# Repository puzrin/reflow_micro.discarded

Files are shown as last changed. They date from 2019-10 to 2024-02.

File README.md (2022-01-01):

Reflow Micro Table
==================




**WIP**

> Simple to build & compact table for hobby projects reflow assembly.

This tool helps to build modern and complicated electronic devices at home.
It's very small, and ideally suits for hobbyists, who assemble PCBs from time to
time an don't wish to keep big reflowers from microwave ovens.

Working area is up to 70\*60mm. That's enougth for almost all hobby PCBs with
SMD components.

- [EasyEDA project page](https://easyeda.com/reflow/reflow-usb-pd-ext) -
  Schematic & PCB. Order everything in couple of clicks.
- [Thingiverse page](https://www.thingiverse.com/thing:4165226) - Case drafts
  for 3d-printer.

Also see project page on [hackaday.io](https://hackaday.io/project/168063-reflow-micro-table).
Until WIP, it tracks progress and has useful tips in build logs.

## Build & usage

- [Assembly guide](doc/assembly.md)
- [User manual](doc/manual.md)

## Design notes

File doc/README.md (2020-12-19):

## Content

- **[assembly.md](assembly.md)** - assembl guide.
- **[heater_assembly.md](troubleshooting.md)** - separate guide for heater build.
- **[manual.md](development.md)** - usage manual.

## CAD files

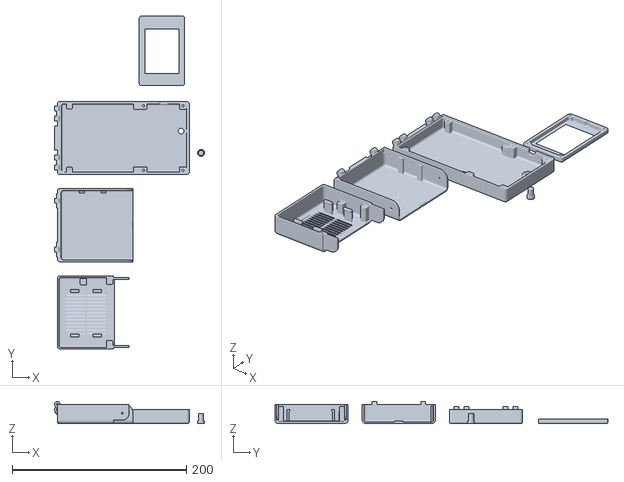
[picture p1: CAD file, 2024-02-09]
3dprint/case.stl
172.3 x 382.0 x 25.4

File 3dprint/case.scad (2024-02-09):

// - Глубину болтов уточнить
include <utils.scad>;

//======================================================================
// Update if other inserts used
// For example, D3.2*3mm
insert_d = 3.6;
insert_h = 4;

magnet_d = 5;
magnet_h = 3;
magnet_x_ofs = 2;
//======================================================================


e = 0.01;
2e = 0.02;

$fn = $preview ? 12 : 48;

wall = 2;
hinges_wall = 4;
right_wall = 2.5;

pcb_wx = 145;
pcb_wy = 80;
pcb_margin = 0.25;
pcb_top_margin = 0.2; // extra space for better close of top cap
pcb_h  = 1.6 + pcb_top_margin;

tray_wx = pcb_wx + hinges_wall + right_wall;
tray_wy = pcb_wy + 2*wall;
tray_h  = 16;

tray_inner_h  = tray_h - wall - pcb_h;

cap1_wx = 87;
cap2_wx = tray_wx - cap1_wx;

cap_inner_h = 20;
cap_h = cap_inner_h + wall;

hinges_d = 6.6;
hinges_shaft_d = 2;
hinges_full_w = 28.0;
hinges_w = 17.0;
hinges_inter_gap = 0.2;
hinges_gap = 0.4;
hinges_section_w = (hinges_w - hinges_inter_gap*2)/3;
hinges_shift = tray_wy/2 - hinges_full_w/2;
hinges_z_correction = 0.1; // Extra Z offset for better case closing

cap_display_mounts_x_shift = -0.0;
cap_display_wx = 52;
cap_display_wy = pcb_wy;
cap_display_inner_h = 4.2;
cap_display_top_wall = 1;
cap_display_h = cap_display_inner_h + cap_display_top_wall;
cap_display_wall = 3;
cap_display_x_inserts_space = 140 - 95;

cap_display_view_wx = 39;
cap_display_view_wy = 51;

case_r_vert = 3;
case_r_bottom = 2;
case_r_top = 4;

btn_base_h = 3;
btn_d = 6.0;
btn_guide_d = btn_d + 0.5 + 6;
pcb_btn_h = 2.7; // Height of button's top point on PCB

module pcb_top(ofs = 0) { tr_y(ofs + pcb_wy/2) children(); }
module pcb_bottom(ofs = 0) { tr_y(ofs - pcb_wy/2) children(); }
module pcb_left(ofs = 0) { tr_x(ofs - tray_wx/2 + hinges_wall) children(); }
module pcb_right(ofs = 0) { tr_x(ofs - tray_wx/2 + hinges_wall + pcb_wx) children(); }

module case_left(ofs = 0) { tr_x(ofs - tray_wx/2) children(); }
module case_right(ofs = 0) { tr_x(ofs + tray_wx/2) children(); }
module case_top(ofs = 0) { tr_y(ofs + tray_wy/2) children(); }
module case_bottom(ofs = 0) { tr_y(ofs - tray_wy/2) children(); }


module m2_screw_hole() {
    translate([0, 0, -e]) {
        cylinder(10, d = 2);
        translate([0, 0, 0.1-e]) cylinder(h = 2, d1 = 4, d2 = 0);
        // Make head outer part long for deep holes
        translate([0, 0, 0.1]) mirror([0, 0, 1]) cylinder(30, d = 4);
    }

}

// Relaxed hole for M2 flat - D 5mm + 2.5mm
module m2_screw_hole_wide() {
    translate([0, 0, -e]) {
        cylinder(10, d = 2.5);
        // Create bigger cone, for extra head dia
        translate([0, 0, 0.1-e-0.236]) cylinder(h = 2.236, d1 = 5, d2 = 0);
        // Make head outer part long for deep holes
        translate([0, 0, 0.1-0.236]) mirror([0, 0, 1]) cylinder(30, d = 5);
    }

}


module fan50_latch(width = 10) {
    translate([width/2, 0.2, -e])
    rotate([0, -90, 0])
    linear_extrude(width)
    polygon([
        [0, 0],
        [11.3, 0],
        [12.8, -1.5],
        [14, -1.5],
        [14, 2],
        [0, 2]
    ]);
}

module fan50_guides() {
    translate([0, -1, 0]) {
        translate([-13, 25, wall]) fan50_latch();
        mirror([1, 0, 0]) translate([-13, 25, wall]) fan50_latch();
        mirror([0, 1, 0]) translate([-13, 25, wall]) fan50_latch();
        rotate([0, 0, 180]) translate([-13, 25, wall]) fan50_latch();

        translate([25, -10, wall - e])
        cube([1.5, 20, 1]);

        mirror([1, 0, 0])
        translate([25, -10, wall - e])
        cube([1.5, 20, 1]);
    }
}

module fan50_hole() {
    rotate([0, 0, -90])
    skew([ 0, 50, 0, 0, 0, 0])
    translate([0, 0, -e])
    rcube([46, 46, wall + 2e], r = 2);
}

module fan50_grill() {
    rotate([0, 0, -90])
    skew([ 0, 50, 0, 0, 0, 0])
    for(i = [-21:4.0:20]) {
        translate([i, -25, 0]) cube([2, 50, 2]);
    }

    translate([-1, -27, 0]) cube([2, 54, 2]);
}

module hinges_add() {
    rotate([-90, 0, 0])
    tr_z(-hinges_w/2)
    hull() {
        cylinder(hinges_w, d = hinges_d);
        cube([hinges_d/2, hinges_d/sqrt(2), hinges_w]);
    }
}

module hinges_substract(second = false) {
    rotate([-90, 0, 0]) {
        // through hole
        cylinder(hinges_w, d = hinges_shaft_d+e, center = true);
        // screw head space
        translate([0, 0, hinges_w/2-e])
        cylinder((hinges_full_w-hinges_w)/2+2e, d = 5.5);
        // screw nut space
        mirror([0, 0, 1])
        translate([0, 0, hinges_w/2-e])
        cylinder((hinges_full_w-hinges_w)/2+2e, d = 5.5);

        if (second == false) {
            cylinder(
                hinges_section_w + hinges_inter_gap*2,
                d = hinges_d + hinges_gap*2,
                center = true
            );
        } else {
            tr_z(hinges_section_w + hinges_inter_gap)
            cylinder(
                hinges_section_w + hinges_inter_gap*2,
                d = hinges_d + hinges_gap*2,
                center = true
            );

            mirror([0, 0, 1])
            tr_z(hinges_section_w + hinges_inter_gap)
            cylinder(
                hinges_section_w + hinges_inter_gap*2,
                d = hinges_d + hinges_gap*2,
                center = true
            );
        }
    }
}

module cap2_hinge() {
    margin = 2;

    rotate_x(90)
    difference() {
        linear_extrude(2)
        hull() {
            translate([-wall, wall + margin]) square(e);
            translate([-wall, cap_h]) square(e);
            translate([cap_inner_h - margin, cap_h]) square(e);

            translate([cap_inner_h/2, cap_inner_h/2+wall, 0])
            circle(cap_inner_h/2 - margin);
        };

        translate([cap_inner_h/2, cap_inner_h/2 + wall, 0])
        cylinder(wall*4, d=2, center=true);
    }
}

module tray_pcb_support(h = tray_h-pcb_h) {
    difference() {
        rcube([7, 7, h], r=1);

        translate([0, 0, h + e])
        mirror([0, 0, 1]) {
            cylinder(insert_h, d = insert_d);
            cylinder(insert_h+5, d = 2.5);
        }
    }
}

module wire_latch() {
    h = cap_h-2;

    rotate([0, 90, 0])
    linear_extrude(6)
    polygon([
        [0, 0],
        [-h, 0],
        [-h, 2],
        [-h+1, 2.5],
        [-h+2, 2],
        [0, 2]
    ]);
}

module magnet_holder(h = 10, wx = 7, wy = 7, md = 5, mh = 3) {
    difference() {
        rcube([wx, wy, h - mh + 0.5]);
        tr_z(h - mh - 0.2) cylinder(h = mh+10, d = md+0.5);
    }
}

module _tray_base() {
    difference() {
        rcube(
            [tray_wx, tray_wy, tray_h],
            r = case_r_vert,
            rbottom = case_r_bottom
        );

        pcb_left(1) pcb_bottom(1) tr_z(wall)
        rcube([pcb_wx-2, pcb_wy-2, tray_h], r=2, rbottom=case_r_bottom, center=false);

        pcb_bottom(-pcb_margin) pcb_left(-pcb_margin) tr_z(tray_h-pcb_h)
        rcube(
            [pcb_wx+pcb_margin*2, pcb_wy+pcb_margin*2, pcb_h+e],
            center=false,
            r=0.01
        );
    }
}


module tray() {
    difference() {
        union() {
            _tray_base();

            // PCB + Display supports (solid, no holes)
            pcb_right(-5) pcb_bottom(3) tr_z(wall)
            rcube([8, 8, tray_h-pcb_h - wall + e]);

            mirror_y()
            pcb_right(-5) pcb_bottom(3) tr_z(wall)
            rcube([8, 8, tray_h-pcb_h - wall + e]);

            pcb_right(-50) pcb_bottom(3) tr_z(wall)
            rcube([8, 8, tray_h-pcb_h - wall + e]);

            mirror_y()
            pcb_right(-50) pcb_bottom(3) tr_z(wall)
            rcube([8, 8, tray_h-pcb_h - wall + e]);

            // Boot0 button guide
            // Height = inner - btn_height - btn_base_h - safety_space
            pcb_right(-7) pcb_top(-32)
            cylinder((tray_h - pcb_h) - pcb_btn_h - btn_base_h - 0.2, d=btn_guide_d);

            // Hinges addons
            case_left() tr_y(hinges_shift) tr_z(tray_h)
            hinges_add();

            mirror_y()
            case_left() tr_y(hinges_shift) tr_z(tray_h)
            hinges_add();

            // Hinge angle limiter
            stopper_w = tray_wy - hinges_full_w*2;
            case_left() tr_z(tray_h)
            rotate_x(90) tr_z(-stopper_w/2)
            linear_extrude(stopper_w)
            polygon([[0,0], [-3,-3.5], [0,-6]]);

            /*case_left() tr_z(tray_h - hinges_d/2)
            rotate([90, 45, 0])
            cube([hinges_d/sqrt(2), hinges_d/sqrt(2), tray_wy - 2*hinges_full_w], center=true);*/
        }

        // Fan wire slot
        pcb_left() pcb_bottom() tr_z(tray_h-pcb_h-5+e)
        cube([4, 2.6, 10]);

        // Boot0 button guide hole
        pcb_right(-7) pcb_top(-32) tr_z(-e)
        cylinder(tray_h, d=btn_d+0.5);

        // Holes in supports for 8mm M2 screws (with 3.3mm display cap inserts)
        pcb_right(-5) pcb_bottom(3) tr_z(tray_h - (8-3.3))
        m2_screw_hole_wide();

        mirror_y()
        pcb_right(-5) pcb_bottom(3) tr_z(tray_h - (8-3.3))
        m2_screw_hole_wide();
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

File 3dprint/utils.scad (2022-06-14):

e = 0.01;
2e = 0.02;


module qfillet(h, r) {
    difference () {
        translate([-e, -e, 0]) cube([r+e, r+e, h]);
        translate([r, r, -e]) cylinder(h+2e, r = r);
    }
}

module torus(r1, r2, $fn = $fn) {
    rotate_extrude(convexity=2, $fn=$fn)
    difference() {
        translate([r1 - r2, 0, 0]) circle(r=r2, $fn=$fn);
        translate([-r2, 0, 0]) square(r2*2, true);
    }
}

module _hooled_toruses(x, y, r_xy, r_z) {
    translate([r_xy, r_xy, 0]) torus(r_xy, r_z);
    translate([x-r_xy, r_xy, 0]) torus(r_xy, r_z);
    translate([r_xy, y-r_xy, 0]) torus(r_xy, r_z);
    translate([x-r_xy, y-r_xy, 0]) torus(r_xy, r_z);
    
    translate([r_z, r_xy, 0]) rotate([-90, 0, 0]) cylinder(y-r_xy*2, r=r_z);
    translate([x-r_z, r_xy, 0]) rotate([-90, 0, 0]) cylinder(y-r_xy*2, r=r_z);
    translate([r_xy, r_z, 0]) rotate([0, 90, 0]) cylinder(x-r_xy*2, r=r_z);
    translate([r_xy, y-r_z, 0]) rotate([0, 90, 0]) cylinder(x-r_xy*2, r=r_z);
    
    translate([r_z, r_z, -r_z])
    rcube([x-r_z*2, y-r_z*2, r_z*2], r = r_xy-r_z, center = false);
}


module rcube(size = [10, 10, 10], center = true, r = 1, rtop = 0, rbottom = 0) {
    x = size[0]; y = size[1]; h = size[2];

    tx = center ? -x/2 : 0;
    ty = center ? -y/2 : 0;

    translate([tx, ty, 0]) {
        if (rtop == 0 && rbottom == 0) {
            translate([r, r, 0]) cylinder(h, r = r);
            translate([x-r, r, 0]) cylinder(h, r = r);
            translate([r, y-r, 0]) cylinder(h, r = r);
            translate([x-r, y-r, 0]) cylinder(h, r = r);
            translate([0, r, 0]) cube([x, y-r*2, h]);
            translate([r, 0, 0]) cube([x-r*2, y, h]);
        }
        if (rtop > 0 && rbottom == 0) {
            translate([0, 0, h-rtop]) _hooled_toruses(x, y, r, rtop);
            rcube([x, y, h-rtop], r = r, center = false);
        }
        if (rtop == 0 && rbottom > 0) {
            translate([0, 0, rbottom]) _hooled_toruses(x, y, r, rbottom);
            translate([0, 0, rbottom])
            rcube([x, y, h-rbottom], r = r, center = false);
        }
        if (rtop > 0 && rbottom > 0) {
            translate([0, 0, h-rtop]) _hooled_toruses(x, y, r, rtop);
            translate([0, 0, rbottom]) _hooled_toruses(x, y, r, rbottom);
            translate([0, 0, rbottom])
            rcube([x, y, h-rbottom-rtop], r = r, center = false);            
        }
    }
}

// skew takes an array of six angles:
// [ x:y, x:z, y:x, y:z, z:x, z:y ]
module skew(dims) {
    matrix = [
        [ 1, tan(dims[0]), tan(dims[1]), 0 ],
        [ tan(dims[2]), 1, tan(dims[3]), 0 ],
        [ tan(dims[4]), tan(dims[5]), 1, 0 ],
        [ 0, 0, 0, 1 ]
    ];
    multmatrix(matrix) children();
}

module rotate_x(angle) { rotate([angle, 0, 0]) children(); }
module rotate_y(angle) { rotate([0, angle, 0]) children(); }
module rotate_z(angle) { rotate([0, 0, angle]) children(); }

module tr_x(ofs) { translate([ofs, 0, 0]) children(); }
module tr_y(ofs) { translate([0, ofs, 0]) children(); }
module tr_z(ofs) { translate([0, 0, ofs]) children(); }

module mirror_y() { mirror([0, 1, 0]) children(); }

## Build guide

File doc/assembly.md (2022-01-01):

Device assembly <!-- omit in toc -->
===============

- [Required components](#required-components)
  - [General](#general)
  - [Optional](#optional)
- [Heater assembly](#heater-assembly)
- [PCB assembly](#pcb-assembly)
- [Firmware upload](#firmware-upload)
- [Case](#case)

## Required components

### General

&nbsp; | Name | Comment
-------|------|--------
1 | [PCB & Components](https://easyeda.com/reflow/reflow-usb-pd-ext) | Go to EasyEda project page and order both in couple of clicks. If you order PCB first, components second - you will be able to join delivery. Add rocker switch below to LCSC order.
2 | [2.4" Display](https://www.aliexpress.com/item/32852776943.html) | 240*320, SPI, ILI9341, touch screen.
3 | [Cooling fan 5010](https://www.aliexpress.com/item/4000194163972.html) |
4 | [22 AWG wire](https://www.aliexpress.com/item/32854919883.html) | Optional, SMT stencil positioning.
5 | [DIN965 M1.6 SS screws 20mm](https://www.aliexpress.com/item/33013472653.html) | Mount heater plate to PCB. Should be stainless steel, important!
6 | [DIN965 M1.6 black screws 8mm](https://www.aliexpress.com/item/4000217127933.html) | MCH mount
7 | [M1.6 SS washers](https://www.aliexpress.com/item/4000222547150.html) | MCH mount
8 | [M1.6 SS spring lock washers](https://www.aliexpress.com/item/4000222556028.html) | MCH mount
9 | [M2 inserts 3mm](https://www.aliexpress.com/item/4000513304304.html) | Case components mount places.
10 | [M2 flat cap screws 14mm](https://www.aliexpress.com/item/4000217127933.html) | Case assembly, cooling fan mount.
11 | [M2 Spring lock washers](https://www.aliexpress.com/item/32982630546.html) | Hinges assembly.
12 | [M2 washers](https://www.aliexpress.com/item/32859516826.html) | Hinges assembly.
13 | [M2 nuts](https://www.aliexpress.com/item/32859946901.html) | Hinges assembly, cooling fan mount.
14 | [M2 flat cap screws 8mm](https://www.aliexpress.com/item/4000217127933.html) | Hinges assembly.
15 | [Mushroom head M2 screws 5mm](https://www.aliexpress.com/item/4000168030333.html) | PCB mount.
16 | [MCH 50\*50\*2mm 150W](https://www.aliexpress.com/item/33005272347.html) | [Alternate](https://www.aliexpress.com/item/32991559341.html). Minimal power at room temp - 130W. For 110 volts buy 300W one.
17 | [Aluminium plate 4mm](https://www.aliexpress.com/item/32998175339.html) | [Alternate](https://www.aliexpress.com/item/32985318306.html).  Heater. You may also wish to buy 2mm plate for shims, if have no circular saw.
18 | Aluminum Foil 50μm (0.05mm) | Heater bottom insulation. Such foil is sold for sauna insulation. You can also try foil from baking forms.
19 | [Aluminium sticky tape](https://www.aliexpress.com/item/33036337241.html) | PCB reflector. You need fat, 50-100um tape, 30-50mm wide. Don't use cheap thin one, it will not work as needed.
20 | Temperature resistant black paint | Coating for heater top.
21 | [Thermal conductive paste](https://www.aliexpress.com/item/32870824982.html) | Should work at 300C. Don't try cheap ones.

Note. You are strongly advised to order SMT stencil for your PCB. That will
add ~ 8$ in total to your order - good price for convenience. On placing stencil
order at jlcpcb, select option "custom size", and set 160\*. Then stencil
will be compact and light, with small delivery cost.

**Important!** If you order SMT stencil, add text note to your order: "**make
stencil according to paste mask file and don't forget corner holes**".

### Optional

See [heater assembly](heater_assembly.md) docs for details. May be you already
have drill stand and so on.

&nbsp; | Name | Comment
-------|------|--------
1 | [Drill bit 1.7mm](https://www.aliexpress.com/item/33023895090.html) | 2 pcs at least, HSS Co (M35) preferable.
2 | [Drill bit 3.1mm](https://www.aliexpress.com/item/33023951160.html) | HSS Co (M35) preferable.
3 | [Miter track](https://www.aliexpress.com/item/32972951062.html) | Drilling conductor
4 | [M6 20mm philips screws](https://www.aliexpress.com/item/32854305389.html) | Drilling conductor
5 | [Aluminum heating plate](https://www.aliexpress.com/item/4000073462890.html) | Paint baking.
6 | [Dimmer](https://www.aliexpress.com/item/32818012686.html) | Regulate heating plate above.
7 | [Mini table saw](https://www.aliexpress.com/item/32845187139.html) | Cut aluminum plates.
8 | Sanding paper | 60, 120, 240, 400 grit

If you are patient enough, you can cut aluminum with hand saw. But circular
saw is much more convenient.

## Heater assembly

All details are  in [separate document](heater_assembly.md) to keep this one
compact.

That's the most boring part. Read is carefully before start making this device.

## PCB assembly

Pin SMT stencil and PCB with 22 AWG wire to silicon pad.

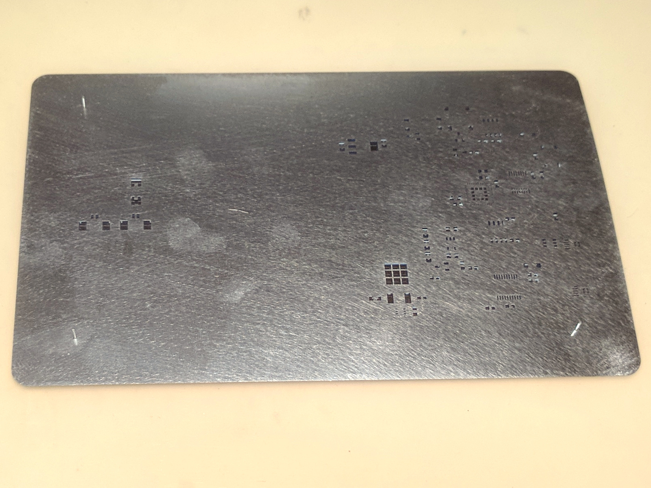
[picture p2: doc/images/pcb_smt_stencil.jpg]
PCB with SMT stencil


Apply soldering paste, place SMD components and solder all with air gun.
Inspect result and fix defects with soldering iron if needed.

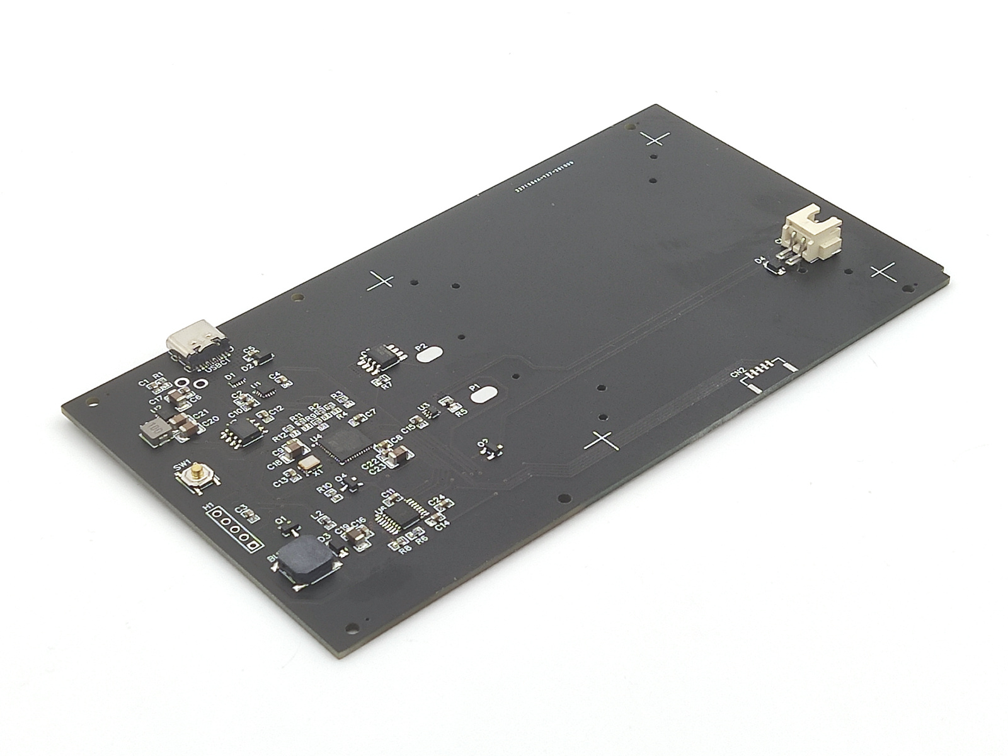
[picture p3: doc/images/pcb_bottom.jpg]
PCB bottom


Cleanup PCB from flux, mount LCD and place sticky aluminum type on area
behind heater.

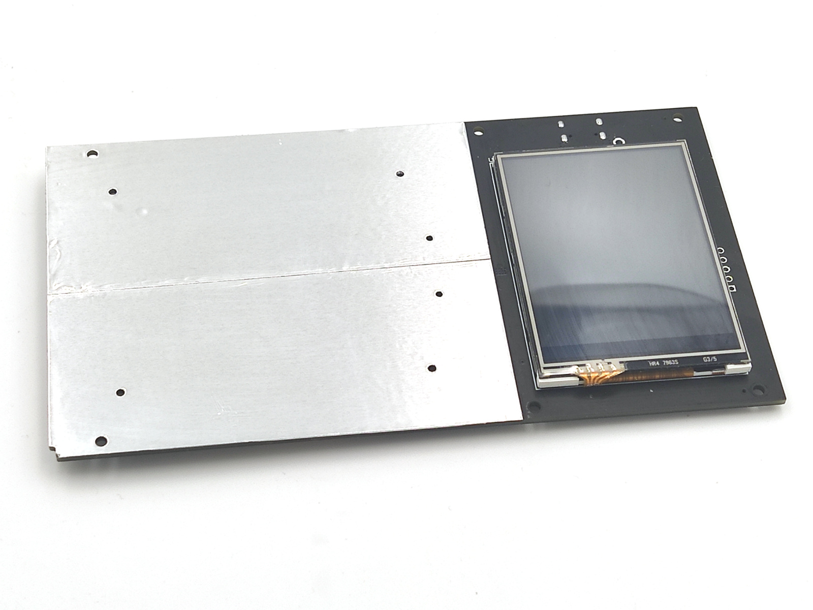
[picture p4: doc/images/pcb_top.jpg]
PCB top


Mount display & heater.

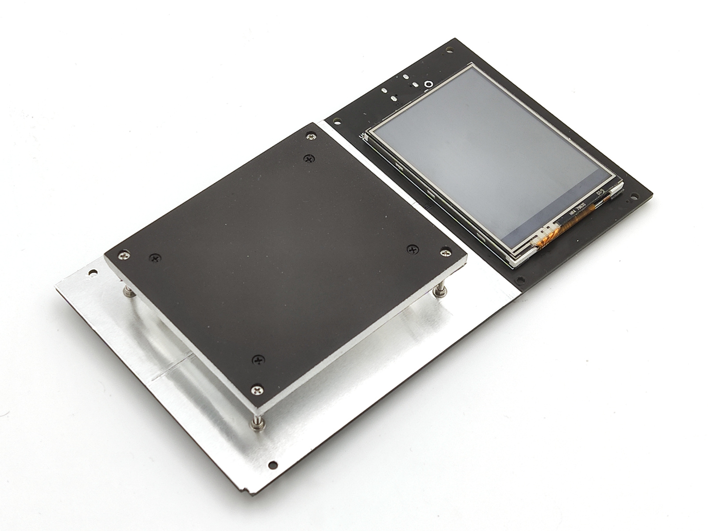
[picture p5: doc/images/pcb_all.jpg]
All mounted


Now everything ready to be flashed and placed into case.

## Firmware upload

TBD

## Case

TBD

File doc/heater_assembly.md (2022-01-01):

Heater assembly <!-- omit in toc -->
===============

- [Intro](#intro)
- [Drilling conductor](#drilling-conductor)
- [Drill plate](#drill-plate)
- [Half-shims for MCH mount](#half-shims-for-mch-mount)
- [Painting](#painting)
- [MCH pads insulation](#mch-pads-insulation)
- [Full assembly](#full-assembly)
- [Mount on PCB](#mount-on-pcb)

## Intro

Everything is designed with accessible materials. But we strongly recommend you
consider [mini circular saw tables](https://www.aliexpress.com/item/32845187139.html)
for easy aluminum cut. Of cause, you can cut it by hand saw, if you are patient.

Also, we recommend you build drilling conductor for ideal drill angle and depth.

## Drilling conductor

That's not mandatory, but simplifies making accurate holes for screws:

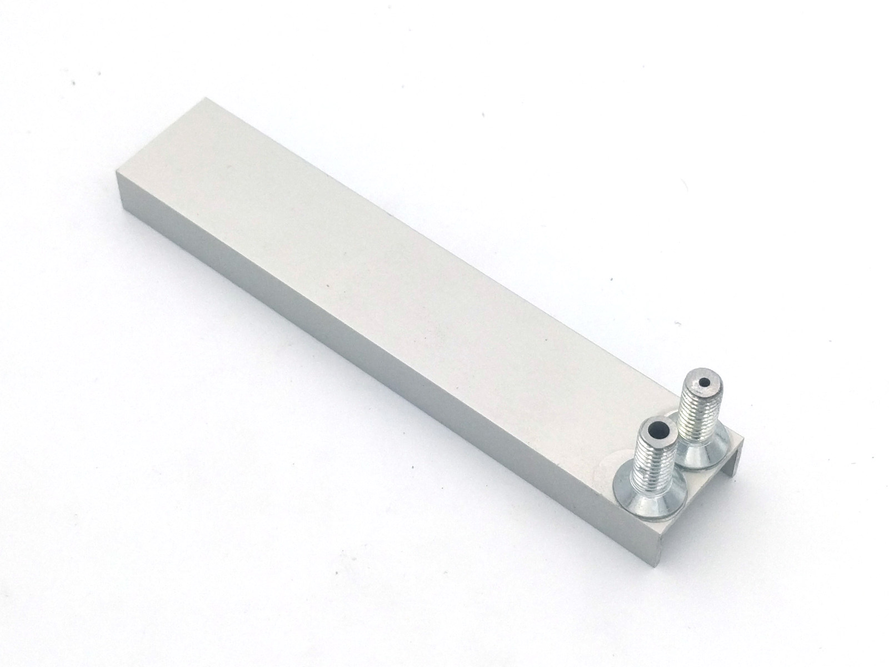
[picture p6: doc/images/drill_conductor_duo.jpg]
Drill conductor


Holes are 1.7mm and 3.1mm (in M6 screws, glued with CA), for appropriate drill bits.

Tips:

1. It's not mandatory to use metal U-profile. Use anything you have,
   even wood. You can also use [miter track](https://www.aliexpress.com/item/33048246472.html).
2. To make hole in M6 screw center - put it into screwdriver, and push with
   drill bit, placed into separate chuck. Philips head is important - no need to
   search center point.
3. To simplify drilling:
    - Use the worst possible screws :). Avoid stainless steel and tempered steel.
    - Add oil to drilled point. If you don't have special one - olive oil will be
      ok.
    - HSS Co (M35, M42) drill bits are more comfortable for steel, instead of
      ordinary HSS. It's also good idea to have reserve drill bits.
4. You may need additional spacer for 3.1mm hole. Drill 2 screws.

After conductor ready, use it to make test holes on unused peace of metal.
Drill 1.7mm hole and then drill 3.1mm cone down until screw sits as needed.
Later, use this to set exact drill bit height in chuck.

## Drill plate

You need 70*60mm plate, 4mm thick. Cut it with circular or hand saw. If you use
[mini table saw](https://www.aliexpress.com/item/32845187139.html) and have no
experience, you should know:

- No need to buy separate saw disc for metal, stock one is ok.
- Add oil to cut area. That's important.
- Train first :). Do couple of test cuts.

Stick plate to PCB with sticky tape, and drill 1.7mm holes to mount MCH and plate
itself. Use conductor above to justify direction.

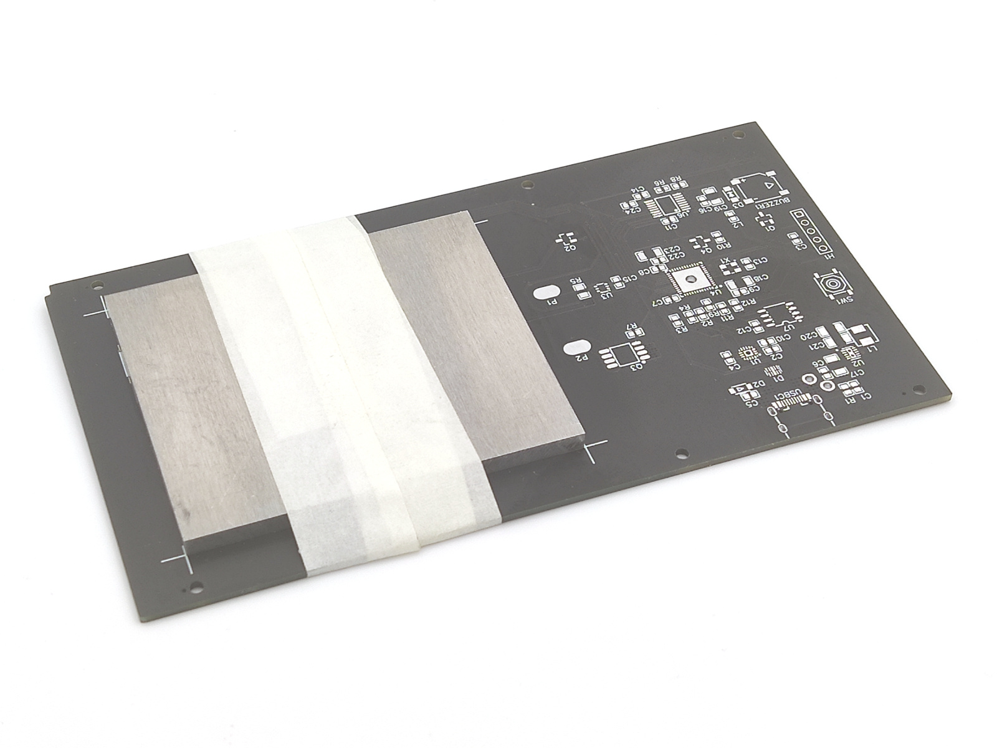
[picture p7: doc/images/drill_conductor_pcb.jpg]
Drill conductor


IMPORTANT. Prior to drill plate, check inner holes. Those are for 49.2 mm MCH.
If your one has different size (48mm or 50mm) - stick MCH to PCB and drill 2 new
conducing holes at the edge opposite to MCH wires.

Now you need to make cones of proper height. Use separate peace of metal and make
0.5mm and 2.0mm deep cones. Repeat until satisfied. Then use test sample to set
exact drill bit height, and make cones in plate:

- 0.5mm deep inner cones (for MCH mount).
- 2.0mm deep outer cones (for mounting to PCB). More deep cones needed to
  increase air gap between PCB.

After all - sand plate to remove artifacts and improve painting quality.

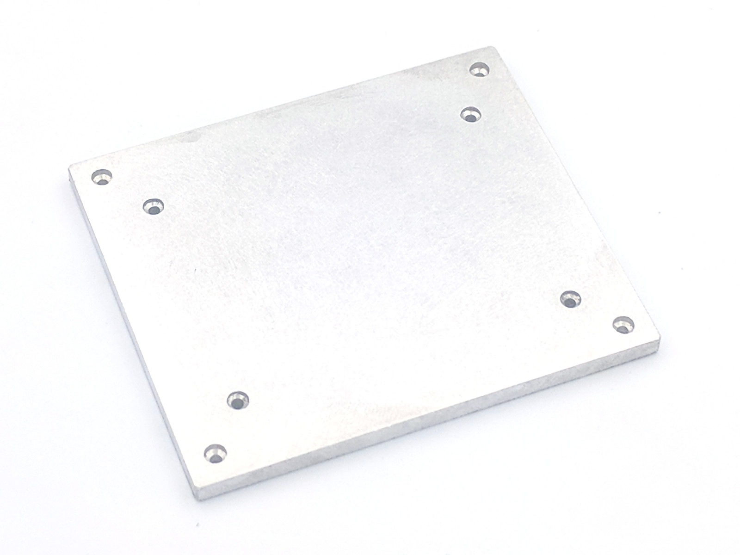
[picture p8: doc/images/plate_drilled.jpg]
Drilled plate


If you have orbital sander - use it. Manual sanding is ok to, but takes more
time.

## Half-shims for MCH mount

MCH is mounted to plate by edges. We need supports from another side of screws
to avoid skew. Those can be done from any peace of 1.5-2.0mm metal. Drill a
series of 2mm holes with step 5mm and margin 3mm from border. Then, at circular
saw, cut the line and split to peaces:

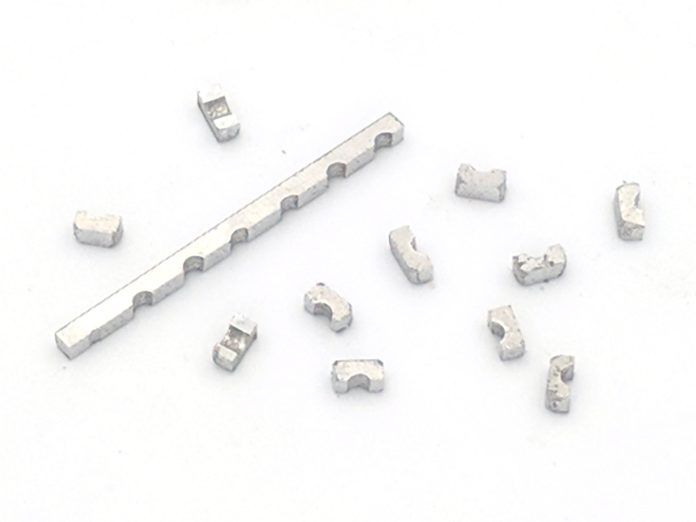
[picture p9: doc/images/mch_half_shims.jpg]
Shims


Round sharp edges to avoid foil damage.

Precision is not critical. Just do as you can :). You can also make half-shims
manually.

## Painting

It's very important to cover heater top with [high temperature black paint](https://www.google.com/search?q=high+temperature+paint), to
increase IR emission. Difference between painted and unpainted surface is HUGE.

We can not give you exact links, but such paints should be widely available in
your local shops. They are used to protect barbecues, car exhaust systems,
furnaces, ovens and so on. Those paints need baking at 200-250C as final step.

IMPORTANT. READ PAINTING PROCESS INSTRUCTION ON AEROSOL. THAT'S IMPORTANT FOR
GOOD RESULT.

You can stick plates with sticky tape to A4 paper. Then to hold it in one hand
and apply aerosol paint by another hand. 2 thin layers are enough.

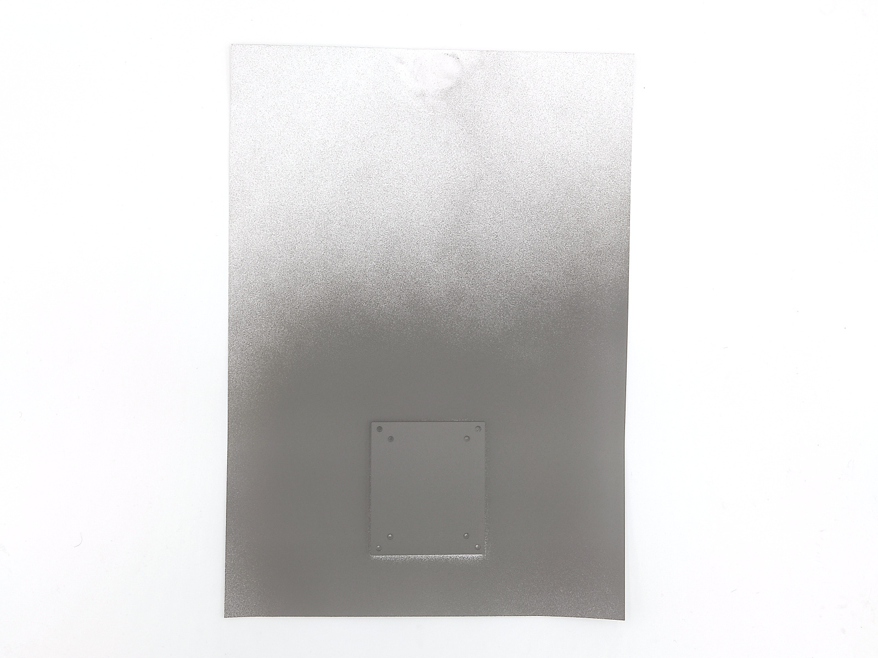
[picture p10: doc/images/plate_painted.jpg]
Painted plate


After paint dries - bake it, according to instructions. If you wish to keep
kitchen oven clean, try [cheap heater](https://www.aliexpress.com/item/32997139401.html)
with light dimmer.

Notes:

- If you have no baking instruction - heat to 100C, then slowly (~ 5C/min)
  to 250C.
- Don't touch paint while bake. It becomes very tender at start.
- Usually, paint starts smoke a 200C, and baking is complete when smoking
  finished. But it worth to bake 1-2 hours more for sure.

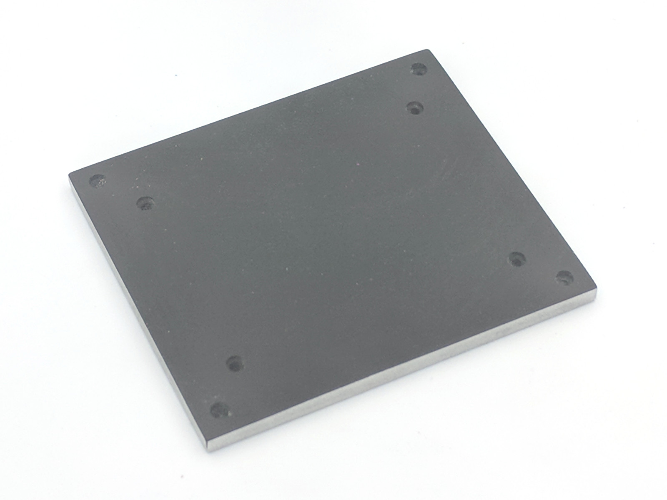
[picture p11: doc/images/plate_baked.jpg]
Baked plate


After baking done - sand border sides, those should not emit heat.

## MCH pads insulation

Since MCH has open pads and been covered by reflector foil, those should be
insulated. This is done by peace of kapton (polyimide) sticky tape.

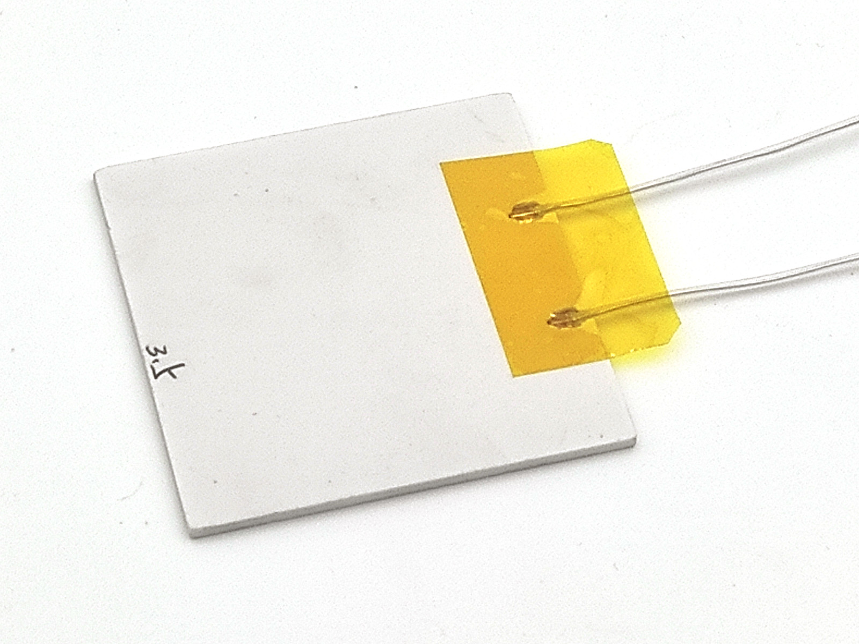
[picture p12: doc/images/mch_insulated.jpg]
MCH insulation


## Full assembly

Here is how heater looks under foil:

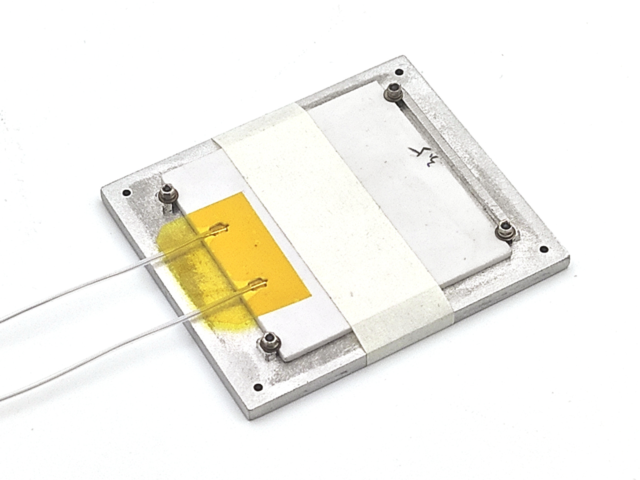
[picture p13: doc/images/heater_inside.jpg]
Heater inside


You need fat aluminum foil, 0.05mm (50um). Such foil is used for sauna thermal
insulation, and available in appropriate stores. If you can's find it - try foil
from food baking forms (straighten it with something round if needed).

Apply thermal conductive paste to plate, put heater to it's place and stick it
temporary with sticky tape. Note, paste should be ok at high temperature. For
example - Thermal Grizzly Kryonaut.

Cut peace with 1cm reserve from each side and drill inner screw holes with
conductor. Screw it from one side, insert half-huts with tweezers and tighten
the screws. Then remove sticky tape and install 2 other screws in similar way.

After 4 inner screws assembled, smooth the foil, drill corner holes and install
long corner screws:

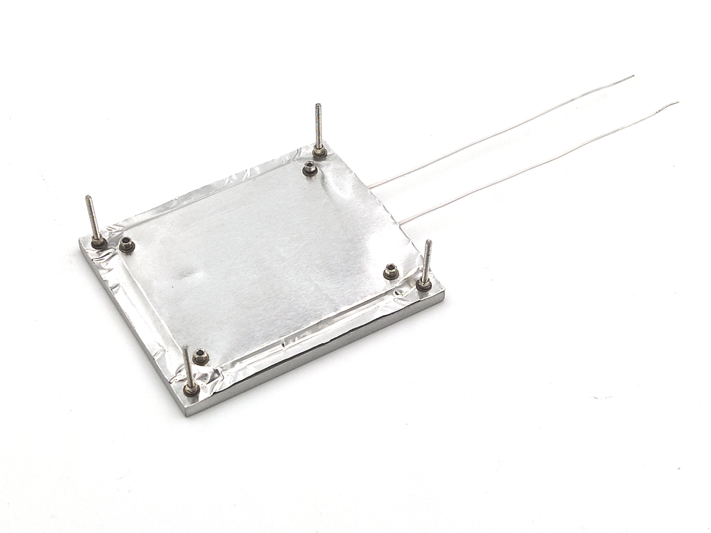
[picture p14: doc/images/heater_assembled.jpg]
Assembled heater


Don't forget to use spring washers everywhere. That's important to compensate
metal parts size change on heating and cooling.

## Mount on PCB

PCB should have additional reflective layer to stay cold. That's done with fat
aluminum sticky tape (0.05-0.1mm). It also help to spread heat from screws.

Cover PCB with aluminum tape under heater, with 1cm outer margin.

PCB top

Then clean everything with IPA and mount assembled heater. Space between
aluminum plate and PCB should be ~13mm.

All mounted

If everything is done right, heater can work unlimited time at 270C while
keeping PCB almost cold.

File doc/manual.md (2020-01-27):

User Manual <!-- omit in toc -->
===========

- [Control](#control)
- [Settings](#settings)

## Reflow mode

TBD

## Preheat mode

TBD

## Settings

TBD

## Calibration

TBD

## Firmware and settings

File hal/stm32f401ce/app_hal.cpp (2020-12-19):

#include "app_gui.h"
#include "app_hal.h"

#include "main.h"
#include "i2c.h"
#include "spi.h"
#include "tim.h"
#include "gpio.h"


extern "C" void SystemClock_Config(void);

namespace hal {

void setup() {
    HAL_Init();
    SystemClock_Config();

    MX_GPIO_Init();
    MX_I2C1_Init();
    MX_I2C3_Init();
    MX_SPI1_Init();
    MX_SPI2_Init();
    MX_TIM2_Init();
    MX_TIM5_Init();

    // Attach display buffer and display driver
    static lv_disp_buf_t disp_buf;
    static lv_color_t buf[LV_HOR_RES_MAX * 50];
    lv_disp_buf_init(&disp_buf, buf, NULL, LV_HOR_RES_MAX * 10);

    lv_disp_drv_t disp_drv;
    lv_disp_drv_init(&disp_drv);
    // TODO:
    //disp_drv.flush_cb = monitor_flush;
    disp_drv.buffer = &disp_buf;
    lv_disp_drv_register(&disp_drv);

    //
    // Init touchscreen
    //
    // TODO


}

//
// Main loop
//

void loop(void)
{
    uint32_t tick_start = HAL_GetTick();

    while(1) {
        uint32_t tick_current = HAL_GetTick();

        if (tick_current - tick_start >= 5)
        {
            // Call ~ every 5ms
            tick_start = tick_current;
        	lv_task_handler();
        }
    }
}


// Enable/Disable LCD backlight
void backlight(bool on)
{
    HAL_GPIO_WritePin(GPIOB, GPIO_PIN_0, on ? GPIO_PIN_SET : GPIO_PIN_RESET);
}

}

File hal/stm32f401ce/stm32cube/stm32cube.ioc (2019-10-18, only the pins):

Mcu.UserName=STM32F401CEUx
PA0-WKUP.Signal=ADCx_IN0
PA1.Signal=ADCx_IN1
PA11.Signal=USB_OTG_FS_DM
PA12.Signal=USB_OTG_FS_DP
PA13.Signal=SYS_JTMS-SWDIO
PA14.Signal=SYS_JTCK-SWCLK
PA3.Signal=S_TIM2_CH4
PA4.Signal=SPI1_NSS
PA5.Signal=SPI1_SCK
PA6.Signal=SPI1_MISO
PA7.Signal=SPI1_MOSI
PA8.Signal=I2C3_SCL
PB0.Signal=S_TIM3_CH3
PB1.Signal=GPIO_Output
PB2.Signal=GPIO_Output
PB3.Signal=SYS_JTDO-SWO
PB4.Signal=I2C3_SDA
PB6.Signal=I2C1_SCL
PB7.Signal=I2C1_SDA
PB8.Signal=S_TIM10_CH1
PB9.Signal=S_TIM4_CH4

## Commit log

2019-11-22 polish pinout and fix hw target build
    [app_hal.cpp]
2019-11-26 add uart & external sensor io
2019-12-24 rework hal & project struct
    [app_hal.cpp]
2020-02-12 docs: update BOM & add final assembly details
2020-02-18 case draft
    [case.scad]
2020-02-19 docs: bom update
2020-02-22 cubmx: remap pins & activate i2c
2020-02-23 update case an BOM after PCB rework
    [case.scad]
2020-02-24 case v2
    [case_old.scad]
2020-02-26 case: hinges rework
    [case.scad]
2020-02-26 case: fan wire latches rework
    [case.scad]
2020-02-27 case: fan wire slot on cap
    [case.scad]
2020-02-29 doc: plate drill clarify
2020-03-12 docs: heater assembly clarify
2020-03-22 doc: bom clarify
2020-04-07 case: update usb slots
    [case.scad]
2020-06-19 doc: PCB assembly
2020-06-23 stm32g target draft
2024-02-09 next iteration fixes
    [case.scad, case.stl]
